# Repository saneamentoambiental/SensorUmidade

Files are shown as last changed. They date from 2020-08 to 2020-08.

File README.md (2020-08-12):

# Sensor Umidade

Projeto monitorar a umidade de solo de vários recipientes através de sensores capacitivos utilizando um único esp8266 controlador.

## Descrição

O GPSA necessitava de um mecanismo para controlar a umidade de recipientes de pesquisa envolvendo solo e minhocas.

Para atender a necessidade foi criado um sistema que envia para o servidor [ubidots] o valor dos sensores conectados no esp8266.
O sistema aceita até 8 sensores, que são controlados através das portas digitais (ligando-os e desligando-os), e configurados através do portal.

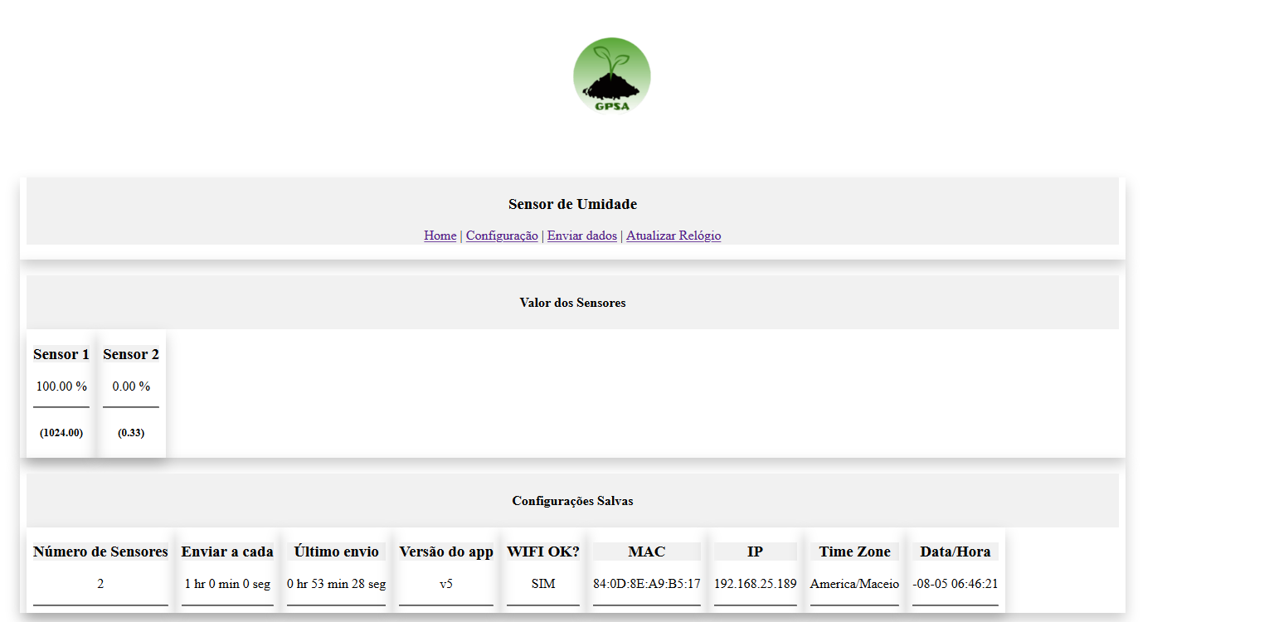
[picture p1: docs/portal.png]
PaginaInicial


## Configuração

### WI-FI

A solução faz uso da *lib* [IotWebConf](https://github.com/prampec/IotWebConf/) para abrir um *portal captive*, que permite o manuseio e configuração da solução.

## Ubidots

A cada período (previamente cadastrada) as informações são enviadas para o servidor Ubidots. Para tal é necessário informar o token do usuário.

Para cada sensor é enviado o valor RAW (como lido do sistema) tendo como faixa 0~1023.

Importante destacar que é preciso fazer a calibração de cada sensor utilizado. No nosso caso fizemos o teste com o solo seco, úmido e saturado. Com estes valores foram criados os gráficos no portal do Ubidots.

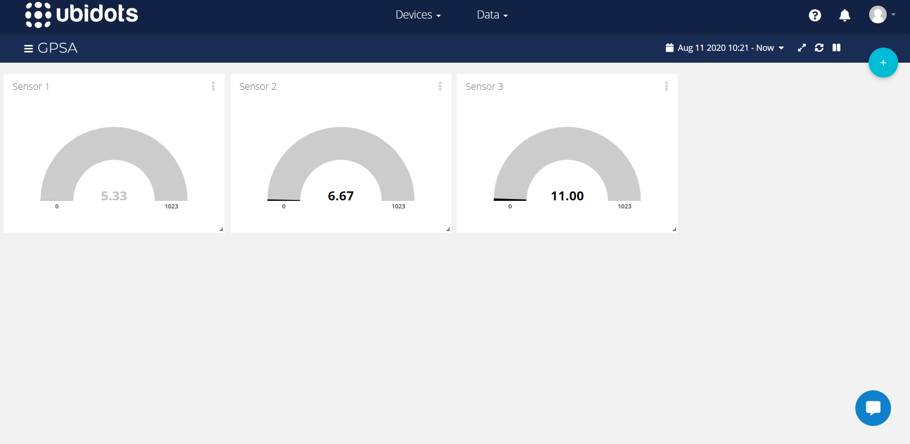
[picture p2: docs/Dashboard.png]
Dashboard Ubidots


### Conexões

A imagem abaixo apresenta o esquema de conexão com 4 sensores, que foi definido através dos pinos `int digitalPinsSoilMoisture[] = {14, 12, 13, 15, 2, 0, 4, 5};`;

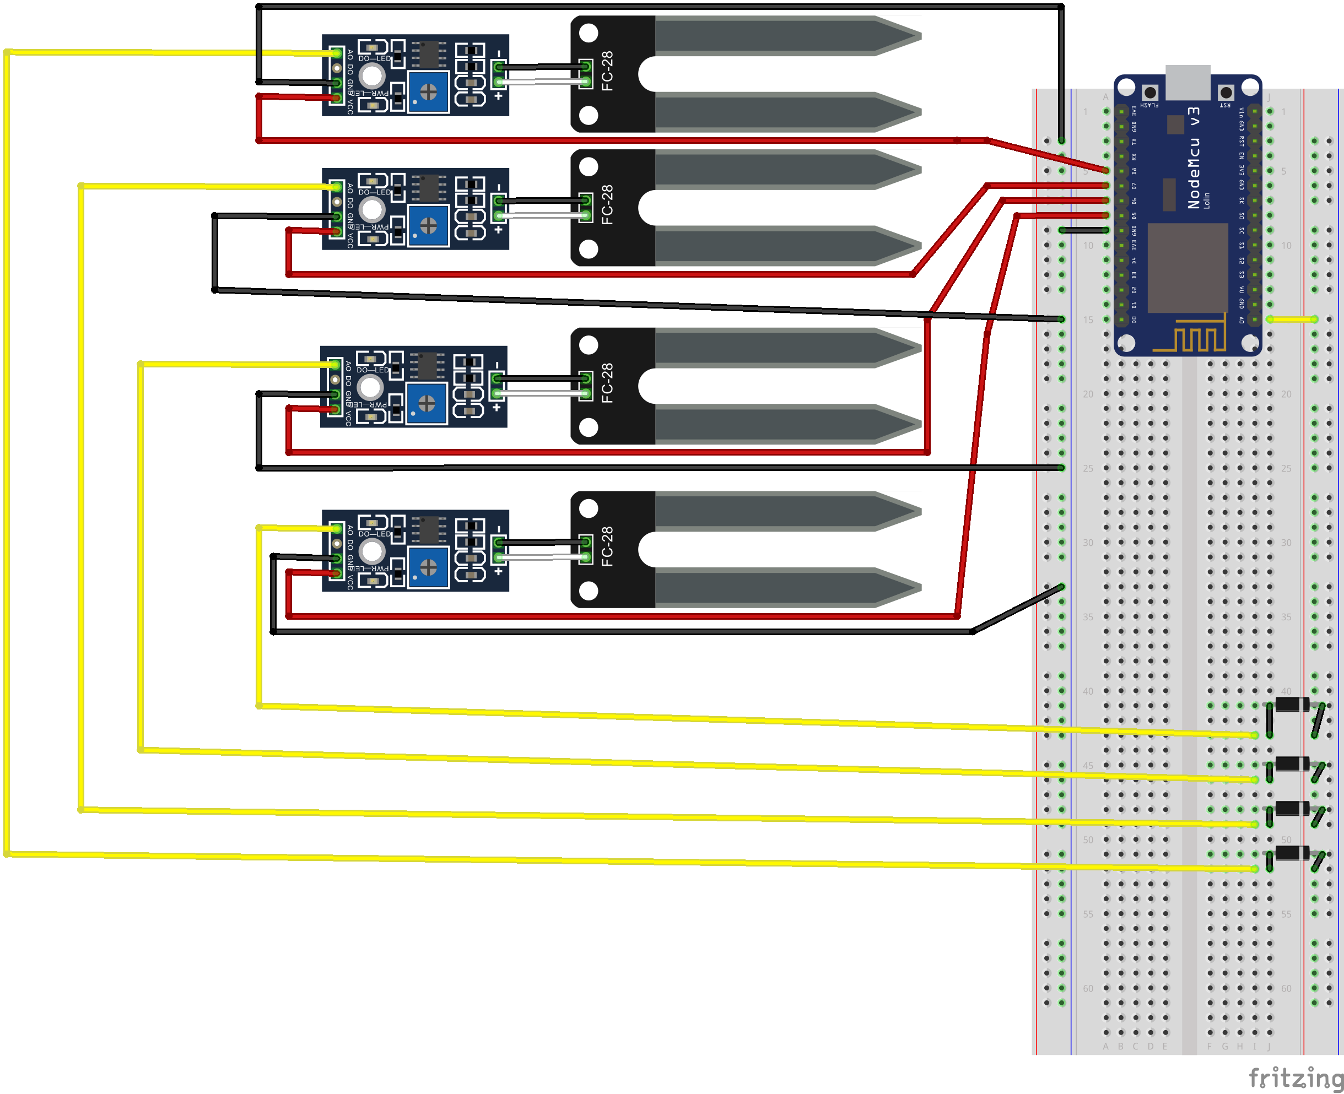
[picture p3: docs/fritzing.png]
Esquema de ligação de sensores
.

A ordem dos pinos definida em `digitalPinsSoilMoisture` representa a posição de cada um dos sensores.

| Sensor | GPIO  |
| :----: | :---: |
| 1 |  14 |
| 2 |  12 |
| 3 |  13 |
| 4 |  15 |
| 5 | 2 |
| 6 | 0 |
| 7 | 4 |
| 8 | 5 |

Ver a definição dos pinos em [aqui](https://camo.githubusercontent.com/565088c2f27742a268695307938112ef42eee995/68747470733a2f2f692e737461636b2e696d6775722e636f6d2f79543468622e706e67).

## API / Exemplo básico

```c++
#include <Arduino.h>
#include <SoilMoistureSensor.h>
#include <SoilMoistureManager.h>

int digitalPinsSoilMoisture[] = {14,12,13,15, 2, 0, 4, 5};
SoilMoistureManager *smm;
int count = 2; // Dois sensores de umidade

setup(){
  smm = new SoilMoistureManager(digitalPinsSoilMoisture, count);
  smm->printStatus();
}

loop(){
  for (unsigned i = 0 ; i < smm->getQtdSensors(); i++){
    char sensor[20], sensorRawValue[20];
    sprintf(sensor,"Sensor_%d", (i));
    sprintf(sensorRawValue,"Sensor_%d_Raw", (i));
    SoilMoistureSensor s = smm->getSensores()[i];
    float value = s.getMoistureValue();
    float rawValue = s.getMoistureRawValue();
    Serial.printf("%s = %f [%f]\n", &sensor, value, rawValue);
  }
  delay(5000);
}
```

## Sensores testados

### GBK 

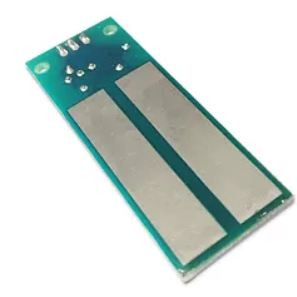
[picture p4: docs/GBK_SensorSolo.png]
Sensor GBK Robotics


- Fazer download do [case](https://www.thingiverse.com/thing:4567970) para impressora 3D.

### Sensor Higrômetro

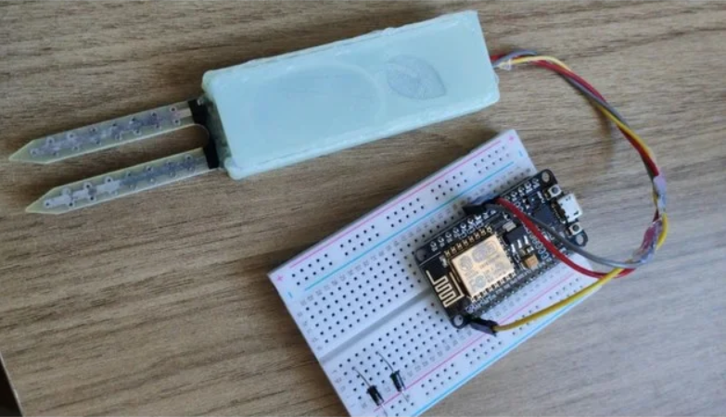
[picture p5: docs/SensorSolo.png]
Sensor


- Fazer download do [case](https://www.thingiverse.com/thing:4562128) para impressora 3D.

---
GPSA: Grupo de Saneamento Ambiental.

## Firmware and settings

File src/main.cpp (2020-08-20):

/**
 * IotWebConf01Minimal.ino -- IotWebConf is an ESP8266/ESP32
 *   non blocking WiFi/AP web configuration library for Arduino.
 *   https://github.com/prampec/IotWebConf 
 *
 * Copyright (C) 2018 Balazs Kelemen <prampec+arduino@gmail.com>
 *
 * This software may be modified and distributed under the terms
 * of the MIT license.  See the LICENSE file for details.
 */

/**
 * Example: Custom HTML
 * Description:
 *   This example demostrates how to override the default look and feel of the
 *   config portal.
 * 
 *   The first customalization is to add a logo to the config page.
 * 
 *   The second customalization is a special javascript, that detects all
 *   password fields, and adds a small button after each of them with a
 *   lock on it. By pressing the lock the password became visible/hidden.
 */

#include <IotWebConf.h>
#include <main.h>

void atualizarVariaveis(){
	timeUbidots = atoi(timeUbidotsValue);
	qtdSensores = atoi(qtdSensoresValue);
}

void configSaved()
{
	atualizarVariaveis();
	//setupUbidots();
	Serial.println("Configuração atualizada.");	
}

boolean formValidator()
{
	Serial.println("Validating form.");
	boolean valid = true;

	if (ubidots && ubidots->wifiConnect(iotWebConf.getWifiSsidParameter()->getId(), iotWebConf.getWifiPasswordParameter()->getId())){
		iotWebConf.getWifiSsidParameter()->errorMessage = "Não foi possível conectar à rede informada.";
		valid = false;
	}
	Serial.println("WIFI.");

	int l = server.arg(tokenUbidotsParam.getId()).length();
	if (l < 5)
	{
		tokenUbidotsParam.errorMessage = "Token inválido!";
		valid = false;
	}

	Serial.println("TOKEN.");

	if( server.arg(qtdSensoresParam.getId()).length() > 0 ){
		int qtd = atoi(server.arg(qtdSensoresParam.getId()).c_str());
		if (qtd < 1 && qtd > 8)
		{
			qtdSensoresParam.errorMessage = "A quantidade de sensores deve ser entre 1 e 8.";
			valid = false;
		}
	}
	Serial.println("Sensores.");

	if ( server.arg(timeUbidotsParam.getId()).length() > 0 ){
		int time = atoi(server.arg(timeUbidotsParam.getId()).c_str());
		if (time < 30 && time > 86400)
		{
			timeUbidotsParam.errorMessage = "O valor deve ser entre 30 (seg) e 86400 (1 dia)!";
			valid = false;
		} else {
			if (time % 30 > 0)
			{
				timeUbidotsParam.errorMessage = "O valor deve ser múltiplo de 30 seg";
				valid = false;
			}
		}
	}
	Serial.println("Configurações estão validas?");
	Serial.println(valid);
	return valid;
}
void connectWifi(const char* ssid, const char* password);
void setupUbidots();
void setupIotWebConf(){
	
	itoa(timeUbidots, timeUbidotsValue, 10);
	itoa(qtdSensores, qtdSensoresValue, 10);


	//iotWebConf.setStatusPin(LED_BUILTIN);


	iotWebConf.getWifiPasswordParameter()->type = "text";
	iotWebConf.addParameter(&separatorUbidots);
	iotWebConf.addParameter(&tokenUbidotsParam);
	iotWebConf.addParameter(&timeUbidotsParam);

	iotWebConf.addParameter(&separatorConfigGeral);
	iotWebConf.addParameter(&qtdSensoresParam);
	iotWebConf.addParameter(&timeZoneParam);

	iotWebConf.setConfigSavedCallback(&configSaved);
	iotWebConf.setFormValidator(&formValidator);
	iotWebConf.setWifiConnectionHandler(&connectWifi);
	// -- Applying the new HTML format to IotWebConf.
	iotWebConf.setHtmlFormatProvider(&customHtmlFormatProvider);
	
	iotWebConf.init();

	
  
}
void connectWifi(const char* ssid, const char* password){
	WiFi.hostname(iotWebConf.getThingName());
	if( WiFi.begin(ssid, password) && ! ubidots )
	//if( iotWebConf.getState() == IOTWEBCONF_STATE_ONLINE && ! ubidots )
	{
		sincronizarRelogio();
		Serial.printf("Hostname = %s\n", WiFi.hostname().c_str());
		debugMsg("Conectado!");		
		setupUbidots();
	}
}

void printStatusUbidots(){
	debugMsg("::::  Info ubidots ::::: ");
	
	if ( ubidots )
	{		
		debugMsg(":: Wifi OK? "); Serial.println(ubidots->wifiConnected());
		debugMsg(":: Server OK? "); Serial.println(ubidots->serverConnected());
		debugMsg(":: IP "); Serial.println(WiFi.localIP());
		debugMsg(":: MAC "); Serial.println(WiFi.macAddress());

	}
	Serial.println("::::  ubidots (END) ::::: ");	
}
void setupUbidots(){
	if (ubidots){
		debugMsg("Dropando ubidots");
		free(ubidots);
		delete ubidots;
		debugMsg("Dropado ubidots");

	}
	debugMsg("Criando ubidots");
	ubidots = new Ubidots(tokenUbidotsValue);
	ubidots->setDebug(EhDebug);	
	//printStatusUbidots();
}
bool sendUbidots(){
	unsigned success = 0;
	for (unsigned i = 0 ; i < smm->getQtdSensors(); i++){
		char sensor[40], sensorRawValue[40];
		sprintf(sensor,"%s_S_%d", iotWebConf.getThingName(), (i));
		sprintf(sensorRawValue,"%s_S_%d_Raw", iotWebConf.getThingName(),  (i));
		SoilMoistureSensor s = smm->getSensores()[i];
		float value = s.getMoistureValue();
		float rawValue = s.getMoistureRawValue();
		if ( EhParaEnviarAoServidor )
		{
			//ubidots->add(sensor, value);
			ubidots->add(sensorRawValue, rawValue);
		} 
		Serial.printf("%s = %f [%f]\n", &sensor, value, rawValue);
		if ( ubidots->wifiConnected() )
		{
			if ( ! EhParaEnviarAoServidor || ubidots->send(iotWebConf.getThingName()))
			{
				success++;
			}
		}
	}

	// for(int i = 1; i <= qtdSensores; i++ ){
	// 	char sensor[20], sensorRawValue[20];
	// 	sprintf(sensor,"Sensor_%d", (i));
	// 	sprintf(sensorRawValue,"Sensor_%d_Raw", (i));


	// 	SensorUmidadeResult resultado;
	// 	obterValorUmidade(i, &resultado);
	// 	if ( resultado.status == SensorUmidade_status_t::ERROR)
	// 	{			
	// 		Serial.printf("%s = %s [\n%c\n]\n", &sensor, resultado.status, resultado.msgError);
	// 		Serial.println(resultado.msgError);
	// 		continue;
	// 	} else {
	// 		if ( EhParaEnviarAoServidor )
	// 		{
	// 			ubidots->add(sensor, resultado.value);
	// 			ubidots->add(sensorRawValue, resultado.rawValue);
	// 		}
	// 	}
	// 	Serial.printf("%s = %f [%d]\n", &sensor, resultado.value, resultado.status);
	
	// 	if ( ubidots->wifiConnected() )
	// 	{
	// 		if ( ! EhParaEnviarAoServidor || ubidots->send(iotWebConf.getThingName()))
	// 		{
	// 			success++;
	// 		}
	// 	}
	// }
	if( success == smm->getQtdSensors() ){
		Serial.println("Ubidots updated.");
		ultimoEnvio = millis()/1000;
		return true;
	} else{
		Serial.printf("Ubidots error(s): \n- %d dos %d foram enviados.", success, qtdSensores);
		return false;
	}
}


void setupSensores()
{	
	smm = new SoilMoistureManager(digitalPinsSoilMoisture, qtdSensores);
}

void setup() 
{
	Serial.begin(9600);
	Serial.println("Starting up...");
	setupIotWebConf();
	
	// -- Set up required URL handlers on the web server.
	server.on("/", handleRoot);
	server.on("/config", []{ iotWebConf.handleConfig(); });
	server.on("/ubidots", pageSendUbidots);
	server.on("/time", pageSincronizarRelogio);
	server.onNotFound([](){ iotWebConf.handleNotFound(); });

	atualizarVariaveis();
	lastMilles = millis();
	
	if( WiFi.isConnected())
	{
		debugMsg("Conectado!");
		setupDateTime();
		sincronizarRelogio();
	}
	setupSensores();
	
	
	Serial.println("Ready.");
}

void loop() 
{
	// -- doLoop should be called as frequently as possible.
	iotWebConf.doLoop();
	
	currentMillis = millis();  //get the current "time" (actually the number of milliseconds since the program started)
	if (currentMillis - lastMilles >= (timeUbidots*1000))  //test whether the period has elapsed
	{
		//debugMsg("Call sendUbidots");
		sendUbidots();
		lastMilles = currentMillis;
	}
}

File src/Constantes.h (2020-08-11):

#ifndef _Constantes_H_
#define _Constantes_H_

#ifndef IOTWEBCONF_CONFIG_USE_MDNS
	#define IOTWEBCONF_CONFIG_USE_MDNS 1
#endif

const bool EhDebug = true;
const bool EhParaEnviarAoServidor = true;
// const bool VersaoDEMO = false;
const bool FormatHD = false;
const bool ResetWIFI = false;
const unsigned int TimeDelay = 5000;
size_t sizeDocument = 100;

void debugMsg(const char* msg){
	if (EhDebug ){
		Serial.println(msg);
	}
}

String formatarBool(bool valor){	
	if ( valor == true){
		return "SIM";
	} 
	return "NÃO";
}
String formatarTempo(int valor){
	int tempo = valor;
	unsigned int hora = tempo / 3600;	
	tempo = tempo - hora * 3600;
	unsigned int min = tempo / 60;
	tempo = tempo - min * 60;
	
	String s = "";
	s += hora;
	s += " hr ";
	s += min;
	s += " min ";
	s += tempo;
	s += " seg";
	return s;
}

//========================
String criarCard(String titulo, String valor)
  {
	String s = "<div class='card row'><h3 class='lg'>";
	s += titulo;
	s += "</h3><p>";
	s += valor;
	s += "</p><hr></div>";
	return s;
  }

  String getMenu(){
	String s = "<a href='/'>Home</a> | <a href='config'>Configuração</a> | <a href='ubidots'>Enviar dados</a> ";
	s += "| <a href='time'>Atualizar Relógio</a>";
	return s;
}

bool between(int value, int min, int max){	
	if (value < min && value > max)
	{
		return false;
	}
	return true;
}

#endif // _Constantes_H_

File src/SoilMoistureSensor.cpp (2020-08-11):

#include <SoilMoistureSensor.h>

SoilMoistureSensor::SoilMoistureSensor(){
	this->status = SoilMoistureSensorStatus::SMSS_OFF;
	pinMode(analogPin, INPUT);

}

void SoilMoistureSensor::setup(int powerPin, unsigned int readQtd, unsigned int analogPin){
	if ( readQtd < 1 ){
		readQtd = 1;
	}
	this->powerPin = powerPin;
	this->analogPin = analogPin;
	this->readQtd = readQtd;
	this->powerOff();
	pinMode(this->powerPin, OUTPUT);
	SoilMoistureSensor();
}


float SoilMoistureSensor::getMoistureRawValue()
{
	powerOn();
	float media = 0;
	for( unsigned int i = 0; i < this->readQtd; i++ ){
		int valor = analogRead(this->analogPin);
		//Serial.println(valor);
		media += valor;
		delayMicroseconds(200);
	}
	powerOff();
	media = media/this->readQtd;
	//Serial.println(media);

	return media;
}

float SoilMoistureSensor::getMoistureValue(const unsigned int in_min, const unsigned int in_max ){
	return map(this->getMoistureRawValue(), in_min, in_max, 100, 0);
	
}
SoilMoistureSensorStatus SoilMoistureSensor::getStatus(){
	return this->status;
}

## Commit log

2020-07-31 Ajustes para reportar sensores de umidade
2020-08-01 Versão que envia para o servidor informações de umidade (valor raw e %) de mais de um sensor
2020-08-01 Remoção do led e do loop da função main
2020-08-01 Correção da definição da quantidade de sensores
2020-08-04 Soil moisture sensor lib
2020-08-12 Fix qtd máxima de sensores
    [main.cpp]
2020-08-12 Correção do tipo de sensor
2020-08-20 - Ajuste na ordem das portas; - Correção do parametro da versão - Correção do nome do device no momento do envio ao Ubidots
